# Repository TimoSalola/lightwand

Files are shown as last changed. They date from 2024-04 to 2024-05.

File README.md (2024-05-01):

# DIY light wand

This repo contains source code for a teensy 4.1 powered DIY light painting wand. I am not a professional nor do I really know what I'm doing. I hope that this repository has value to those who are attempting similar projects. This project works as is, but I would suggest doing some improvements and changes on your own wand based on your own prefences and requirements.

Also C sucks and I suck at C. Code is likely to have major bugs and contain bad practices. It works, it doesn't crash and so on, but I can't confidently say I'd know why it works. Memory leaks and so on are a possibility, but they just don't crash the controller because it has enough memory.

# Components and tools:

### Components used

- Teensy 4.1(chosen for on board sd slot and cpu speed).
- High density(144/m) 5V sk9822 addressable RGB strip(any Fast led compatible rgb strip should work).
- Aluminium led profile with frosted/milky diffuser.
- Various resistors for buttons.
- OLED display(SSD1306).
- 4 buttons.
- SD card.
- 5\*7cm prototype board.
- Smaller proto boards.
- 2.54mm male/female header pins.
- 2 Pre-soldered usb c ports with 4 pins.
- 12V USB C PD trigger board.
- 12V to 5V regulated DC transformer.
- 2x USB C to USB C cables.
- powerbank(with USB C PD).
- Wire, solder.

### Tools

- Soldering iron
- Solder sucker
- Multimeter
- 3D printer
- Clear epoxy

Simplified wiring diagrams and pictures of the controller are in docu_pics folder.

# Issues encountered during development

## Power input and stability

First prototypes had a lot of issues due to connectivity issues with a breadboard. Would advide against using them for anything more complex.

USB power banks hate unstable power draw. Only a small fraction of all tested powerbanks worked on the original hardware revision without USB C PD boards. Going from high power draw to near zero cuts power off, this is most likely caused by the power bank thinking that it has fully charged the device. Similarly most power banks don't charge low power devices, meaning that when LEDs are off, the power bank may turn off.

Managed to solve stability issues by using a 12V 3A PD board and a high current 9-16V to 5V regulated voltage converter. These are fairly cheap and I would encourage either using one of these or going with a 5V 3A trigger board instead.

If a strip is rated at 40W/m at 100% power, this means 100% brightness RGB white. Drawing images is unlikely to draw nearly as much and so matching power supply with strip ratings is not necessary. Even a 5V 3A or 15W power delivery system is likely to work well.

With 1m wands:
5V 1A is enough for working in dark spaces but will most likely not be enough to use the full brightness range of the led strip.
5V 3A is much better and should work well with most images and brightness levels.
5V 7A or the 12V PD trigger + 12V to 5V converter setup should work for 2m wands at high brightness settings.

## Code issues

Memory handling in c++ is a complete mystery to me. Original code did not clear images from memory after using them and this caused rapid teensy crashes. The memory of a variable can overflow over the memory of some other variable, causing odd behavior. C++ must have ways for handling issues like this, but I'm not familiar enough with the language to be aware of them yet.

# Photography tips

Iso 100, f1.8, 8 sec exposure and a 3 stop ND filter has proven to be a good starting point when taking light painting shots. Without nd filter, ambient light overexposes shots at wide apertures and this is fairly limiting. Variable nd filters are worth considering, but anything darker than nd8(3 stop) is unlikely to be useful.

The following shot of Ronja Lauton(@avaruusronja) was taken at f5, 8s, 100 iso, 16mm.

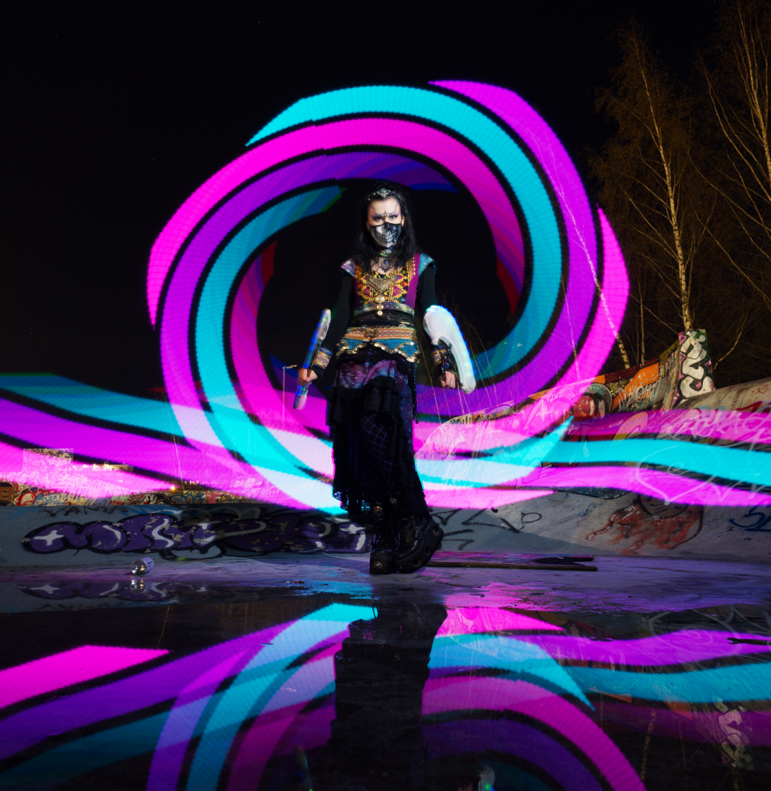
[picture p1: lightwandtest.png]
Wand test with Avaruusronja(Ronja Lauton)


You can remove the led diffuser for extra brightness whenever needed. Depending on pixel density, type and so on this might even look good.

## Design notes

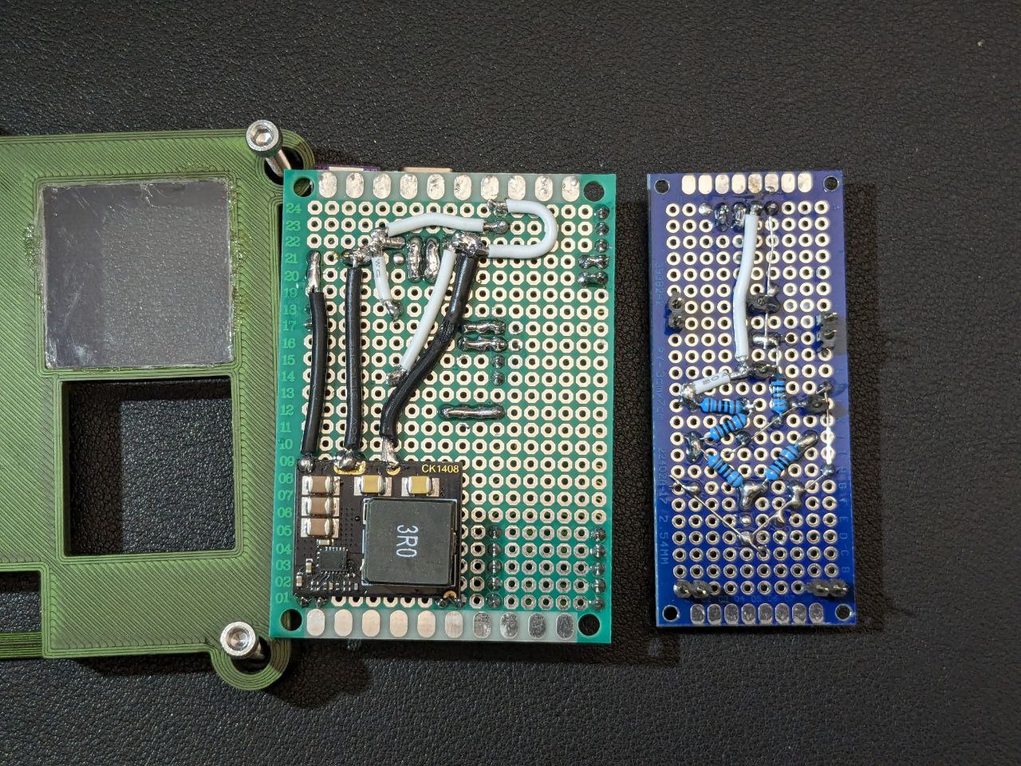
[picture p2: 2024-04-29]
docu_pics/boards_backside.jpg

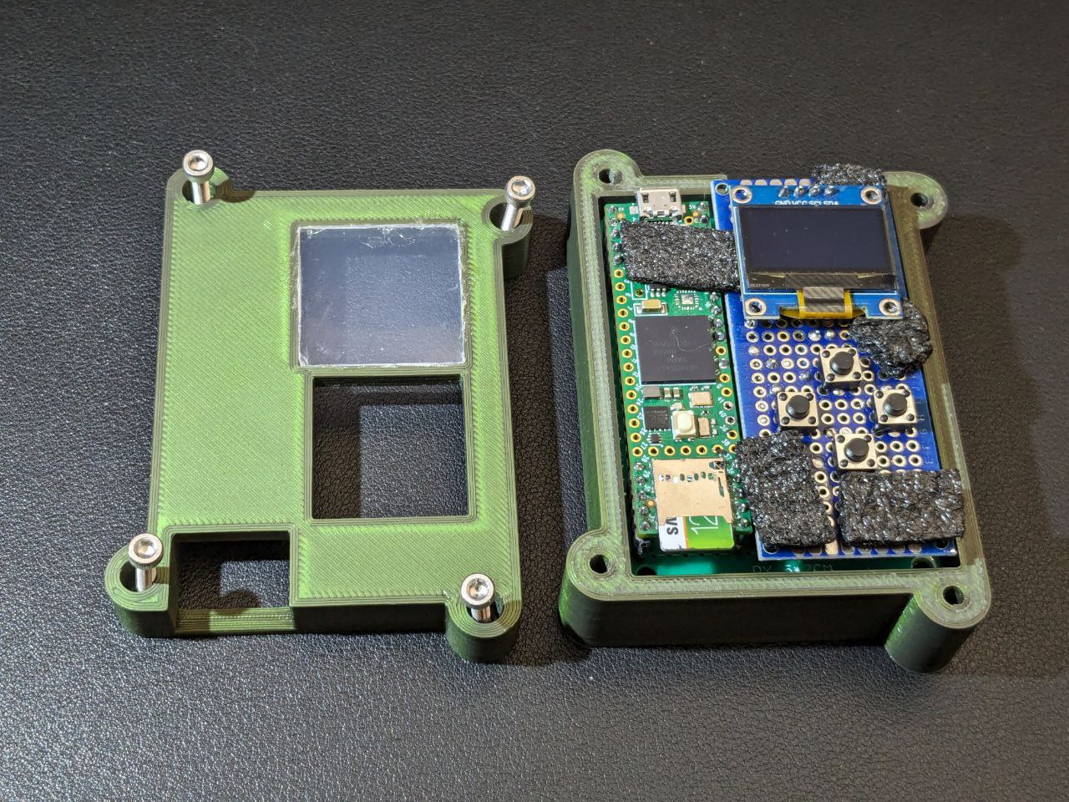
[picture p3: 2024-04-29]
docu_pics/board_in_case.jpg

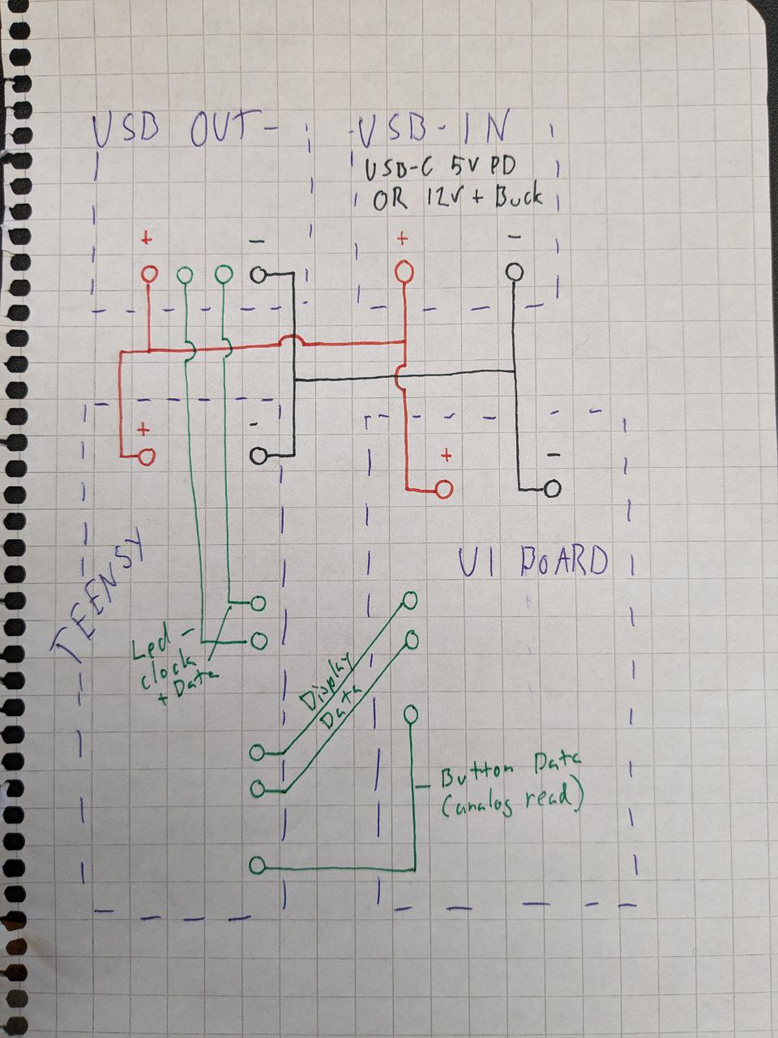
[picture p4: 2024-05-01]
docu_pics/diagram_motherboard.jpg

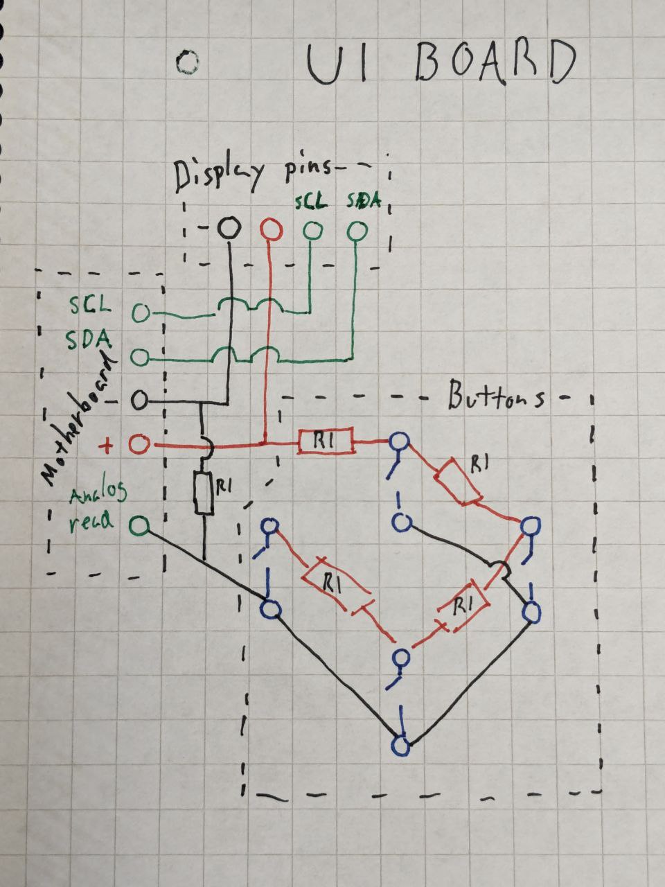
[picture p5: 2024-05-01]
docu_pics/diagram_uiboard.jpg

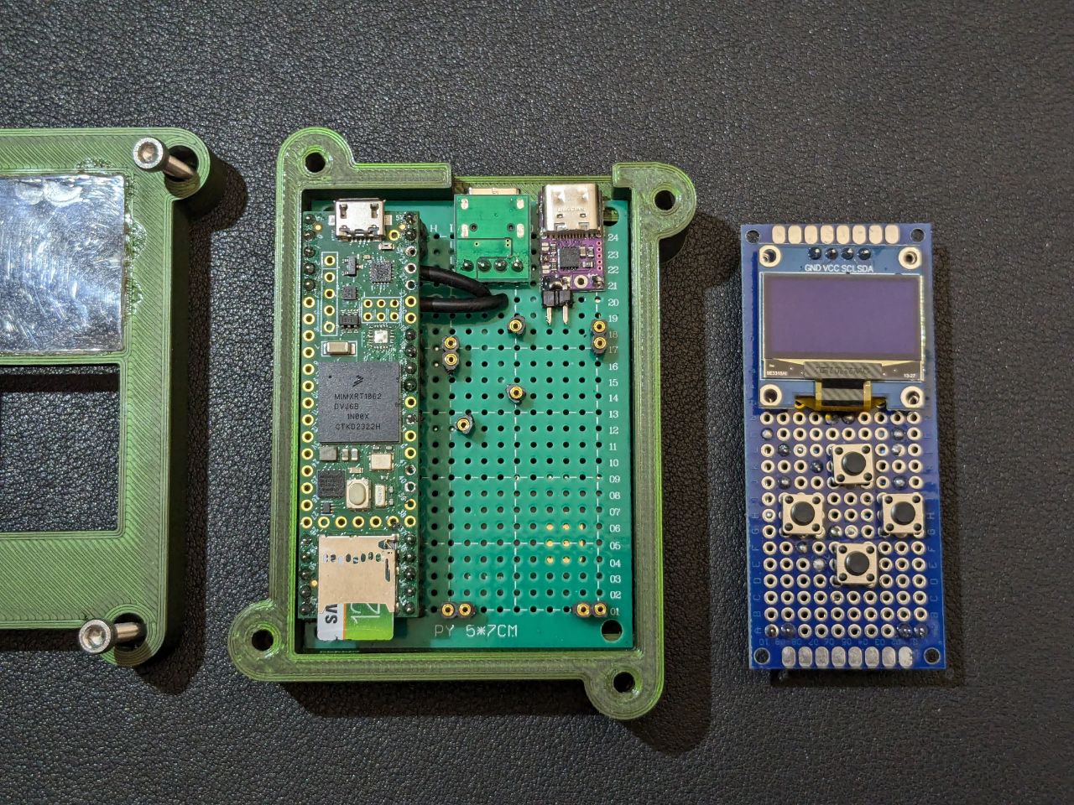
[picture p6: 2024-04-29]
docu_pics/boards_separated.jpg

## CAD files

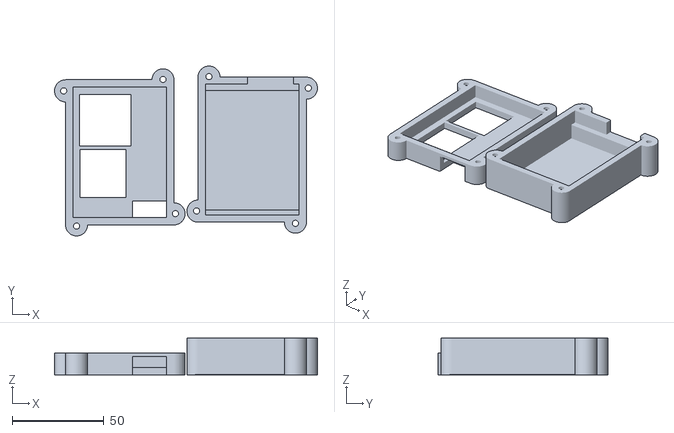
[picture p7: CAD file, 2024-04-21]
lightstick case rev2.stl
143.0 x 92.4 x 20.0

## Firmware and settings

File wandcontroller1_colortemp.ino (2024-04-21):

// importing classes from this project
#include "oled.h"
#include "sd_reader.h"
#include "led_controller.h"

// digital button version, not in use, uncomment pin mode commands in void setup if changing to digital pin readouts.
//const int buttonUp = 22;     // CORRECT
//const int buttonDown = 40;   // CORRECT
//const int buttonLeft = 41;   // CORRECT
//const int buttonRight = 23;  // CORRECT


static int img_index = 0;
const char* file_name;


// fastled doesn't seem to have support for black body color temps, using enumerators instead
int ctemp_enum = 2;

// brightness range in fastled goes from 0 to 255
int brightness_now = 10;


// ######################## global instances of classess
oled* ol = nullptr;
sd_reader* sr = nullptr;
led_controller* lc = nullptr;


void setup() {

  // button setup

  //pinMode(buttonUp, INPUT);
  //pinMode(buttonDown, INPUT);
  //pinMode(buttonLeft, INPUT);
  //pinMode(buttonRight, INPUT);

  //sd_reader sr;
  //led_controller lc;
  //oled ol;
  ol = new oled();
  sr = new sd_reader();
  lc = new led_controller();


  Serial.begin(9600);
  Serial.println("setup");

  main_menu();
}

int read_btn_state() {
  int sensorValue = analogRead(A0);
  //Serial.println(sensorValue);

  // 745 is up
  // 492 right
  // 369 down 
  // 295 left
  // nobtn = 0


  if (sensorValue > 700 && sensorValue < 800){
    // up
    return 1;
  }

  if (sensorValue > 450 && sensorValue < 550){
    // right
    return 2;
  }
  if (sensorValue > 330 && sensorValue < 400){
    return 3;
  }

  if (sensorValue > 250 && sensorValue < 330){
    return 4;
  }

  return 0;

}

int read_btn_verified(){
  // reads button value and verifies that value is not "transitional"
  // eq function waits and attempts to read again if a button is most likely being held down

  int state1 = read_btn_state();

  if (state1 == 0){
    return 0;
  } else {

    delay(50);

    int state2 = read_btn_state();

    if (state1 == state2){
      Serial.println(state1);
      return state1;
    }

  }

  return 0;

}


void settings_menu() {  //oled ol, sd_reader sr
  Serial.println("############################################");
  Serial.println("#################SETTINGS MENU##############");
  Serial.println("############################################");

  delay(1000);

  int settings_item = 0;

  while (true) {
    /*
    // Button layout
    //    1
    //4   0   2
    //    3

    Menu items:
    exit 0 
    brightness 1
    speed 2
    img 3
    color temp 4
    */


    //################################ EXIT MENU LEFTRIGHT BEGINS
    // EXIT menu
    if (settings_item == 0){
      int menu_item_delta = settings_exit_loop();

      if (menu_item_delta == 2){
        break;
      } else{
        settings_item += menu_item_delta;
      }
    }

    //################################ BRIGHTNESS MENU LEFTRIGHT BEGINS
    // brightness menu
    if (settings_item == 1){
      int menu_item_delta = brightness_select_loop();
      settings_item += menu_item_delta;
    }

    //################################ SPEED MENU LEFTRIGHT BEGINS
    if (settings_item == 2){
      int menu_item_delta = cms_select_loop();
      settings_item += menu_item_delta;
    }
    //################################ IMG SELECT MENU LEFTRIGHT BEGINS
    if (settings_item == 3){
      int menu_item_delta = img_select_loop();
      settings_item += menu_item_delta;
    }
    //################################ CTEMP SELECT LEFTRIGHT BEGINS
    if (settings_item == 4){
       int menu_item_delta = ctemp_select_loop();
      settings_item += menu_item_delta;
    }

    // settings item overflow/underflow handling
    if (settings_item > 4){
      settings_item = 0;
    } else if (settings_item < 0){
      settings_item = 4;
    }

  }
}

int settings_exit_loop(){
  Serial.println("Entering exit loop");

  ol->settings_exit();

  lc->clear();
  lc->show();
  delay(600);

  int btn = 0;

  while(true){
    btn = read_btn_verified();
    delay(50);
    if (btn == 2 or btn == 4){
        return 2;
      } else if (btn == 1){
        return -1;
      } else if (btn == 3){
        return 1;
      }
  }
}


int brightness_select_loop(){
  Serial.println("Entering brightness selector loop");

  lc->brightness_visual();

  // drawing menu for the first time
  ol->settings_brightness(brightness_now, 255);

  delay(600);
  // delaying after so that menu item is not instantly changed

  // button value
  int btn = 0;

  while(true){

    // reading btn value
    btn = read_btn_verified();
    delay(50);

    if (btn == 2){
      // right btn pressed, next brightness
      update_brightness(5);
      ol->settings_brightness(brightness_now, 255);
      lc->brightness_visual();
      delay(20);
    } else if (btn == 4){
      update_brightness(-5);
      ol->settings_brightness(brightness_now, 255);
      lc->brightness_visual();
      delay(20);
      // left btn pressed, previous ctemp
    } else if (btn == 1){
      // pressing up, previous menu item
      return -1;
    } else if (btn == 3){
      // pressing down, next menu item
      return 1;
    }

  }


}

void update_brightness(int delta){
  brightness_now += delta;

  if (brightness_now < 1) {
    brightness_now = 1;
  } else if (brightness_now > 255){
    brightness_now = 255;
  }

  lc->update_brightness(brightness_now);


}

int cms_select_loop(){
  // clearing wand
  lc->clear();
  lc->show();

  // drawing menu for the first time
  int cms = lc->get_cms();
  ol->settings_speed(cms);
  

  delay(600);
  // delaying after so that menu item is not instantly changed

  // button value
  int btn = 0;


  int pixel_position = 0;
  int delaytime = 7;

  // while true loop
  while(true){

    // reading btn value
    btn = read_btn_verified();
    if (btn != 0){
      delay(50);
    }


    lc->clear();
    lc->pixel_at_x_to_rgb(pixel_position, 255, 255, 255);
    lc->pixel_at_x_to_rgb(pixel_position-1, 255, 119, 0);
    lc->pixel_at_x_to_rgb(pixel_position-2, 204, 95, 0);
    lc->pixel_at_x_to_rgb(pixel_position-3, 153, 71, 0);
    lc->show();
    pixel_position +=1;

    if (pixel_position > 140){
      pixel_position = 0;
    }

    if (btn == 2){
      // increasing speed
      int current_cms = lc->get_cms();

      int new_speed = current_cms;

      if (current_cms == 50){
        new_speed = 100;
        delaytime = 7;
      }else if (current_cms == 100){
        new_speed = 200;
        delaytime =3;
      }
      lc->set_cms(new_speed);
      ol->settings_speed(new_speed);
    } else if (btn == 4){
      // decreasing speed
      int current_cms = lc->get_cms();
      int new_speed = current_cms;
      if (current_cms == 100){
        new_speed = 50;
        delaytime = 14;
      }else if (current_cms == 200){
        new_speed = 100;
        delaytime = 7;
      }

      lc->set_cms(new_speed);
      ol->settings_speed(new_speed);

    } else if (btn== 1){
      return -1;
    } else if (btn == 3){
      return 1;
    }

    delay(delaytime);
  }



}

int img_select_loop(){

  // clearing wand
  lc->clear();
  lc->show();

  // drawing menu for the first time

  Serial.print("drawing img menu, at index: ");
  Serial.println(img_index);

  const char* im_name = sr->file_n_name(img_index);

  Serial.print(", im name:");
  Serial.println(im_name);
  ol->settings_img_select(im_name);

  delay(600);
  // delaying after so that menu item is not instantly changed

  // button value
  int btn = 0;

  // while true loop
  while(true){

    // reading btn value
    btn = read_btn_verified();
    delay(50);

    if (btn == 2){
      // right btn pressed, next image
      update_img_index(1);

      Serial.print("drawing img menu, at index: ");
      Serial.println(img_index);

      const char* im_name = sr->file_n_name(img_index);

      Serial.print(", im name:");
      Serial.println(im_name);

      ol->settings_img_select(im_name);

      delay(200);
    } else if (btn == 4){
      update_img_index(-1);

      Serial.print("drawing img menu, at index: ");
      Serial.println(img_index);

      const char* im_name = sr->file_n_name(img_index);

      Serial.print(", im name:");
      Serial.println(im_name);

      ol->settings_img_select(im_name);

      delay(200);
      // left btn pressed, previous image
    } else if (btn == 1){
      // pressing up, previous menu item
      return -1;
    } else if (btn == 3){
      // pressing down, next menu item
      return 1;
    }

  }

}

int ctemp_select_loop(){
  Serial.println("Entering ctemp selector loop");

  lc->ctemp_visual();


  // drawing menu for the first time
  ol->settings_ctemp(ctemp_enum);

  delay(600);
  // delaying after so that menu item is not instantly changed

  // button value
  int btn = 0;

  while(true){

    // reading btn value
    btn = read_btn_verified();
    delay(50);

    if (btn == 2){
      // right btn pressed, next ctemp
      update_ctemp_enum(1);
      ol->settings_ctemp(ctemp_enum);
      Serial.println("Ctemp incremented");
      lc->ctemp_visual();
      delay(200);
    } else if (btn == 4){
      update_ctemp_enum(-1);
      ol->settings_ctemp(ctemp_enum);
      ol->show();
      Serial.println("ctemp decreased");
      lc->ctemp_visual();
      delay(200);
      // left btn pressed, previous ctemp
    } else if (btn == 1){
      // pressing up, previous menu item
      return -1;
    } else if (btn == 3){
      // pressing down, next menu item
      return 1;
    }

  }


}

void update_ctemp_enum(int delta){
  // updates ctemp enum and makes sure it does not exceed acceptable range

  int new_ctemp = ctemp_enum + delta;
  Serial.print("New ctemp:");
  Serial.println(new_ctemp);

  if (new_ctemp < 0){
    new_ctemp = 0;
  }

  if (new_ctemp > 8){
    new_ctemp = 8;
  }

  lc->update_ctemp(new_ctemp);

  ctemp_enum = new_ctemp;
}


void update_img_index(int delta){
  // updates image index and makes sure it does not exceed acceptable range

  Serial.print("Updating image index, currently on ");
  Serial.print(img_index);
  Serial.print(" going to ");
  Serial.println(img_index + delta);
  int max_file_count = sr->get_file_count();

  Serial.print("file count: ");
  Serial.println(max_file_count);

  int new_index = img_index + delta;

  if (new_index >= max_file_count){
    Serial.print("Attempted to set file index as:");
    Serial.print(new_index);
    Serial.print(" this is too high. Using last file index:");
    Serial.println(max_file_count-1);
    img_index = max_file_count-1;
  } else if (new_index < 0){
    Serial.print("Attempted to set file index as:");
    Serial.print(new_index);
    Serial.print(" this is too low. Using 0.");
    img_index = 0;
  } else {
    img_index = new_index;
  }

  //updating file name in common variables
  file_name = sr->file_n_name(img_index);

}


void main_menu() {

  Serial.println("############################################");
  Serial.println("##################MAIN MENU#################");
  Serial.println("############################################");

  //sd_reader sr;
  //oled ol;

  const char* img_name = sr->file_n_name(img_index);

  Serial.println("############################################");
  Serial.println("##############SHOWING MAIN MENU#############");
  Serial.println("############################################");
  Serial.println("#FILE: ");
  Serial.println(img_name);

  ol->show_main_menu(img_name);

  while (true) {
    // Main menu loop for print, print with delay, settings and loop selection
    int button_state = read_btn_verified();

    if (button_state == 1) {
      Serial.println("Pressing up.");
      print_once_with_11s_delay(img_name);
    }

    if (button_state == 2) {
      Serial.println("Pressing right. Looping img.");
      print_img(img_name, true);
      delay(300);
    }

    if (button_state == 3) {
      Serial.println("Pressing down.");
      settings_menu();
      // returning from settings menu, some variables have to be updated + menu drawn again.


      img_name = sr->file_n_name(img_index);
      ol->show_main_menu(img_name);
      delay(300); // just got back from another menu, slight delay before accepting another button press
    }
    
    if (button_state == 4) {
      Serial.println("Pressing left. Printing img once.");
      Serial.print("Img index: ");
      Serial.print(img_index);
      Serial.print(" img name: ");
      Serial.println(img_name);
      print_img(img_name, false);
    }

  }
}

void print_once_with_11s_delay(const char* img_name) {

  /*
  Shows a 10 segment timer on wand, 1 segment per second. 
  Delays a second after last segment. Results in a 11 second timer, should go nicely with 10 second timers on cameras
  */


  // 11 second timer
  for (int i = 10; i >= 0; i--) {
    Serial.println(i);
    lc->use_as_progress_bar(i, 10);
    delay(1000);
  }

  // image printing, no looping
  print_img(img_name, false);
}

void print_img(const char* img_name, bool loop) {
  /*
  Prints img with given name. luna.bmp for example. 
  If loop = true, will print image again and again until a button is held down between prints.
  */

  int width = 10;
  int height = 10;

  int* width_pointer = &width;
  int* height_pointer = &height;

  // init pixel array, has to be deleted later
  uint8_t* imgArray = {};

  int framedelay = lc->get_frame_delay();


  // ################# opening img from sd card
  if (sr->loadBMP(img_name, imgArray, width_pointer, height_pointer)) {
    Serial.print("Got file size:");
    Serial.print(*width_pointer);
    Serial.print("x");
    Serial.println(*height_pointer);


    while (true) {
      for (uint16_t y = 0; y < height; y++) { // used to be height


        lc->clear();
        lc->show();

        for (uint16_t x = 0; x < width; x++) { // used to be width

          int arrayPos = ((width * y) + x) * 3;

          uint8_t red = imgArray[arrayPos];
          uint8_t green = imgArray[arrayPos + 1];
          uint8_t blue = imgArray[arrayPos + 2];

          lc->pixel_at_x_to_rgb(x, red, green, blue);
        }

        Serial.print("On row ");
        Serial.print(y);
        Serial.print(" of ");
        Serial.println(height);


        lc->show();
        delay(framedelay);
      }

      // if button held down or if was not supposed to loop, break loop
      int btn = read_btn_state();

      if (btn != 0) {
        break;
      }

      if (!loop) {
        break;
      }
    }

    // loop ends
  }

  // file closes

  // clearing pixels from wand
  lc->clear();
  lc->show();

  // releasing image array from memory
  delete[] imgArray;
}


void loop() {
  //read_btn_state();
  main_menu();
}

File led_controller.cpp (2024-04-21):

#include <FastLED.h>

#include "led_controller.h"

// How many leds in your strip?
#define NUM_LEDS 140

#define DATA_PIN 2
#define CLOCK_PIN 3

int brightness = 25; // default is 25
//int max_brightness = 50;

// how fast to update pixel values in image drawing 
int cm_per_s = 100; // how many cm/ per second the wand is supposed to be moved
int speed_case = 3; // which speed case we are on
int delay_in_us = 1000; // delay between frames in microseconds


int gamma2[] = {0, 0, 0, 0, 0, 0, 0, 0, 0, 0, 0, 0, 0, 0, 0, 0, 1, 1, 1, 1, 1, 1, 1, 2, 2, 2, 2, 2, 3, 3, 3, 3, 4, 4, 4, 4, 5, 5, 5, 5, 6, 6, 6, 7, 7, 7, 8, 8, 9, 9, 9, 10, 10, 11, 11, 11, 12, 12, 13, 13, 14, 14, 15, 15, 16, 16, 17, 17, 18, 18, 19, 19, 20, 20, 21, 22, 22, 23, 23, 24, 25, 25, 26, 27, 27, 28, 29, 29, 30, 31, 31, 32, 33, 33, 34, 35, 36, 36, 37, 38, 39, 40, 40, 41, 42, 43, 44, 44, 45, 46, 47, 48, 49, 50, 50, 51, 52, 53, 54, 55, 56, 57, 58, 59, 60, 61, 62, 63, 64, 65, 66, 67, 68, 69, 70, 71, 72, 73, 74, 75, 76, 77, 79, 80, 81, 82, 83, 84, 85, 87, 88, 89, 90, 91, 93, 94, 95, 96, 97, 99, 100, 101, 102, 104, 105, 106, 108, 109, 110, 112, 113, 114, 116, 117, 118, 120, 121, 122, 124, 125, 127, 128, 129, 131, 132, 134, 135, 137, 138, 140, 141, 143, 144, 146, 147, 149, 150, 152, 153, 155, 156, 158, 160, 161, 163, 164, 166, 168, 169, 171, 172, 174, 176, 177, 179, 181, 182, 184, 186, 188, 189, 191, 193, 195, 196, 198, 200, 202, 203, 205, 207, 209, 211, 212, 214, 216, 218, 220, 222, 224, 225, 227, 229, 231, 233, 235, 237, 239, 241, 243, 245, 247, 249, 251, 253, 255};

// Define the array of leds
CRGB leds[NUM_LEDS];

#define TEMPERATURE1 Candle // 1900  / 0 
#define TEMPERATURE2 0xffac5f // 2200  / 1
#define TEMPERATURE3 Tungsten40W // 2600   2 
#define TEMPERATURE4 Tungsten100W //2850   3
#define TEMPERATURE5 Halogen // 3200       4
#define TEMPERATURE6 CarbonArc //5200       5 
#define TEMPERATURE7 HighNoonSun //5400        6
#define TEMPERATURE8 DirectSunlight // 6000      7
#define TEMPERATURE9 OvercastSky // 7000          8


led_controller::led_controller(){
  FastLED.addLeds<APA102, DATA_PIN, CLOCK_PIN, BGR>(leds, NUM_LEDS);
  update_brightness(25);
  FastLED.setTemperature(TEMPERATURE3);
  set_cms(100);

}

void led_controller::update_brightness(int new_brightness){
  Serial.println("new brightness");
  Serial.println(new_brightness);
  
  FastLED.setBrightness(new_brightness);
  brightness = new_brightness;
}

void led_controller::update_ctemp(int ctemp_enum){

  if (ctemp_enum == 0){
    FastLED.setTemperature(TEMPERATURE1);
  } else if (ctemp_enum == 1){
    FastLED.setTemperature(TEMPERATURE2);
  }else if (ctemp_enum == 2){
    FastLED.setTemperature(TEMPERATURE3);
  }else if (ctemp_enum == 3){
    FastLED.setTemperature(TEMPERATURE4);
  }else if (ctemp_enum == 4){
    FastLED.setTemperature(TEMPERATURE5);
  }else if (ctemp_enum == 5){
    FastLED.setTemperature(TEMPERATURE6);
  }else if (ctemp_enum == 6){
    FastLED.setTemperature(TEMPERATURE7);
  }else if (ctemp_enum == 7){
    FastLED.setTemperature(TEMPERATURE8);
  }else if (ctemp_enum == 8){
    FastLED.setTemperature(TEMPERATURE9);
  }

}

void led_controller::ctemp_visual(){

  clear();
  pixel_at_x_to_rgb(131, 255, 255, 255);
  pixel_at_x_to_rgb(132, 255, 255, 255);
  pixel_at_x_to_rgb(133, 255, 255, 255);
  pixel_at_x_to_rgb(134, 255, 255, 255);
  pixel_at_x_to_rgb(135, 255, 255, 255);
  pixel_at_x_to_rgb(136, 255, 255, 255);
  pixel_at_x_to_rgb(137, 255, 255, 255);
  pixel_at_x_to_rgb(138, 255, 255, 255);
  pixel_at_x_to_rgb(139, 255, 255, 255);
  pixel_at_x_to_rgb(140, 255, 255, 255);
  show();
}

void led_controller::brightness_visual(){
  clear();
  pixel_at_x_to_rgb(0, 255, 255, 255);
  pixel_at_x_to_rgb(1, 255, 255, 255);
  pixel_at_x_to_rgb(2, 255, 255, 255);
  pixel_at_x_to_rgb(3, 255, 255, 255);
  pixel_at_x_to_rgb(4, 255, 255, 255);
  show();
}

int led_controller::get_cms(){
  return cm_per_s;
}

int led_controller::get_frame_delay(){
  return delay_in_us;
}

void led_controller::set_cms(int cms){
  cm_per_s = cms;
  delay_in_us = 1000/(cms/0.7);
}


void led_controller::x_pixels_to_value(int x, int r,int g,int b){
  fill_solid(leds, x, CRGB(r,g,b));
  FastLED.show();


}

void led_controller::startupLEDsTest() {

  // 8 leds 0.17A at 255 bightness. 
  // 600ma max 24 leds
  // startup blink test to confirm LEDs are working.
  //int BRIGHTNESS = 15;

  //8 leds 0.05A at 50 brightness
  // 96 leds max at 500ma?
  // 72 leds at 60 brightness 0.278A, color shift
  // 50 max with 144 leds, uses 1.6A

  FastLED.setBrightness(brightness);
  fill_solid(leds, NUM_LEDS, CRGB(255,0,0));  // fill red
  FastLED.show();
  delay(5000);
  fill_solid(leds, NUM_LEDS, CRGB(0,255,0));  // fill green
  FastLED.show();
  delay(5000);
  fill_solid(leds, NUM_LEDS, CRGB(0,0,255));  // fill blue
  FastLED.show();
  delay(5000);
  fill_solid(leds, NUM_LEDS, CRGB(255,255,255));  // fill white
  FastLED.show();
  delay(5000);
  FastLED.clear();
  FastLED.show();
  FastLED.setBrightness(10);
}

void led_controller::clear(){

  //fill_solid(leds, NUM_LEDS, CRGB(0,0,0));  // fill black
  // FastLED.show();
  FastLED.clear();
}

void led_controller::show(){
  FastLED.show();
}


void led_controller::use_as_progress_bar(int n, int of){

  int leds = NUM_LEDS;

  int leds_on = (leds*n)/of;

  Serial.print("leds on:");
  Serial.println(leds_on);

  clear();

  for (int i = 0; i < leds_on; i++){
    pixel_at_x_to_rgb(i,255, 119,0 );
  }

  show();
}

void led_controller::pixel_at_x_to_rgb(int x, int r, int g, int b){

  leds[x].r = gamma2[r];
  leds[x].g = gamma2[g];
  leds[x].b = gamma2[b];
}
